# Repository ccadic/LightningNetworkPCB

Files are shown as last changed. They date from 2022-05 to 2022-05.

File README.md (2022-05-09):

# LightningNetworkPCB
This is a lightning network esp32S2 experimentation PCB (POS/ATM)

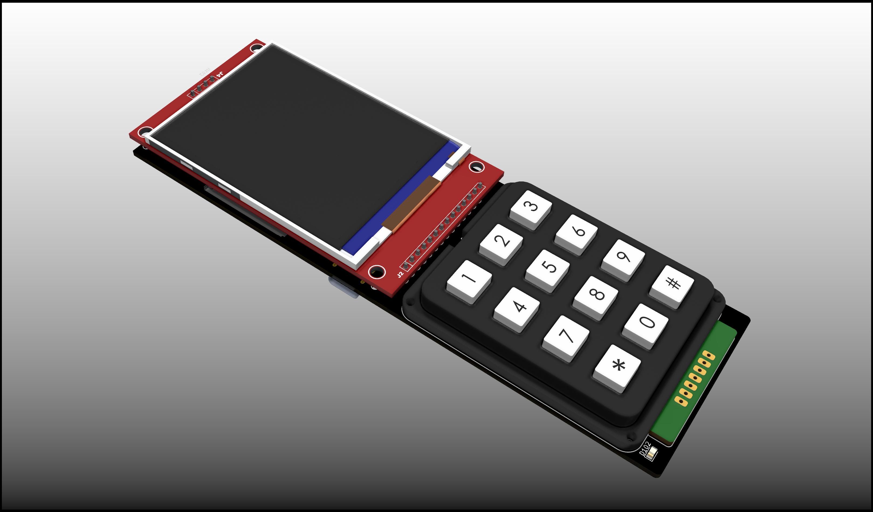
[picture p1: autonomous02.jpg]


Licence is GPL3 I never read :) But philosophy is: do what you want with it. 
If you want to encourage me, here is my BTC wallet address: bc1qdy8alfz6t623trqzk2m0mzrz8w87wwgjc9azgc
My LN Wallet: lnbc1p38nqhcpp5dr46a44fh3jh4uhenvvuxhza30jzzg2auevfjff3hw0uxne34k8qdqu2askcmr9wssx7e3q2dshgmmndp5scqzpgxqyz5vqsp5hzff9unn0vs4f9qsam9a67ffl5hydvs7n4yxd2n6f3aa29qd9jks9qyyssq4y6nllz8ku0qk05glep3g6frwyypptjahnv4t9neszszl07pl944seglzcfk7q9hreuq62wl3f8jjn4ugytncnhhm3zngr34ektzegspkv3cxk

This board is using
An ESP32-S2 wroom chip from espressif
A 2.8 inch touch screen (ILI9341 SPI)
A 3x4 keypad (https://www.amazon.fr/gp/product/B07GFDKJYZ/ref=ppx_yo_dt_b_asin_title_o08_s00?ie=UTF8&th=1)

The board is equiped with a USB-C plug to bring 5V and to upload ESP32S2 scketches
The board also has a 12v regulator thru a barrel jack, should you want to connect a 12v source and fee the coin selector with 12v.  The 12v si also converted to 3.3v for the ESP32 to run.

You have a connector for the CH-926 Coin selector. Have a look at the PCB writing (the wiring is explained)
The CH-926 coin pin is 5V. I built a level shifter to be able to talk to the ESP32 pin in 3.3v

You also have a bunch of extra GPIO / SPI and I2C connector on the top back of the PCB. It allows you to connect a TTL thermal printer, should you want to create a LN-POS
You also have extra ESP32-S TRX1 TRX0 pins to talk to another devive thru UART. I have added these to be able to talk to a CAM-ESP32, should you want to read QR code from another ESP32 device
You hace I2C SDA/SCL pins to connect, for instance, a NFC reader/writer to process payments.

Have fun

Dr Philippe CADIC
pcadic(at)gmail.com

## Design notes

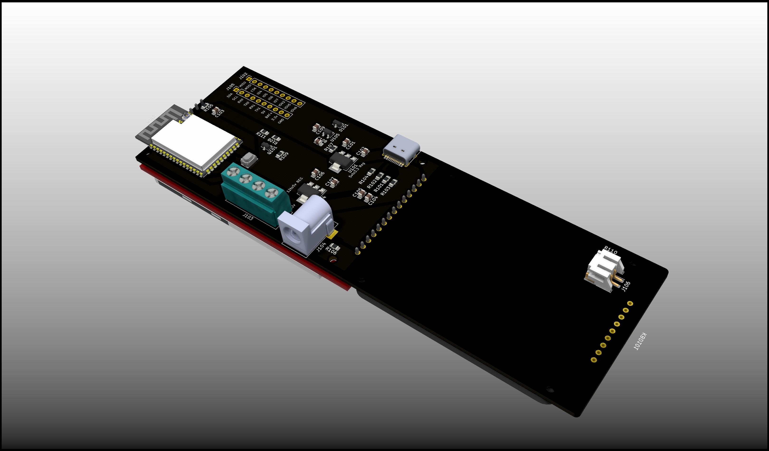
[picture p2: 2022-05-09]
autonomous3.jpg

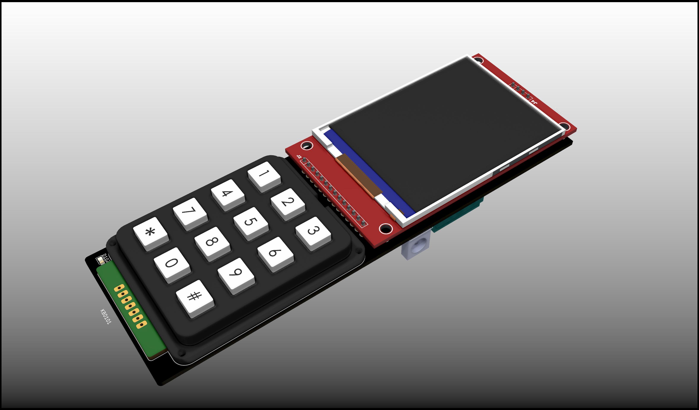
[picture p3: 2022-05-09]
autonomous2.jpg

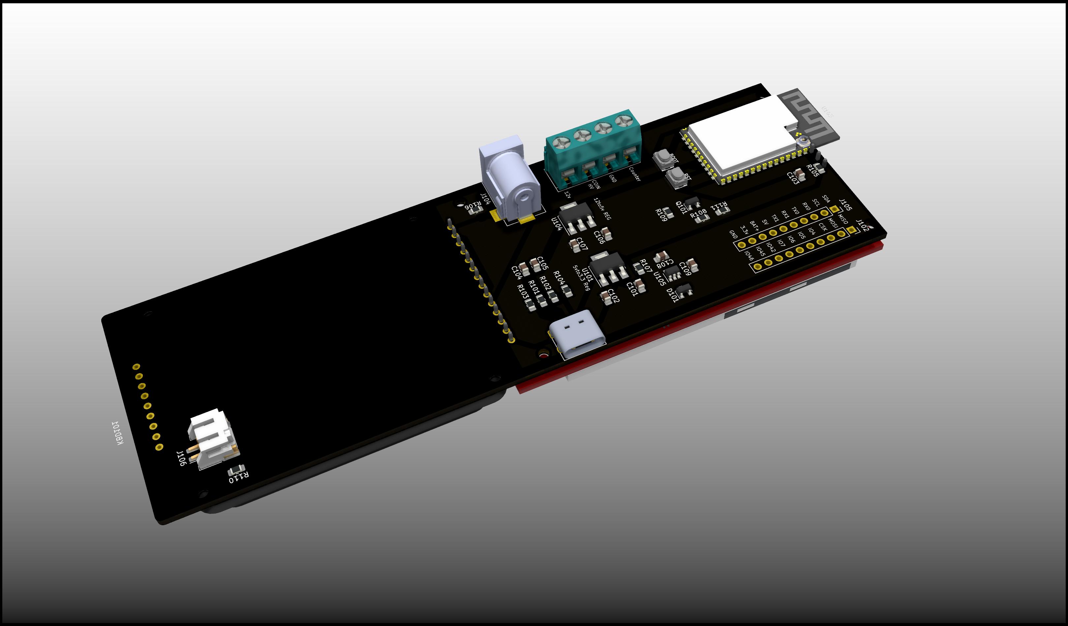
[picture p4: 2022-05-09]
autonomous.jpg

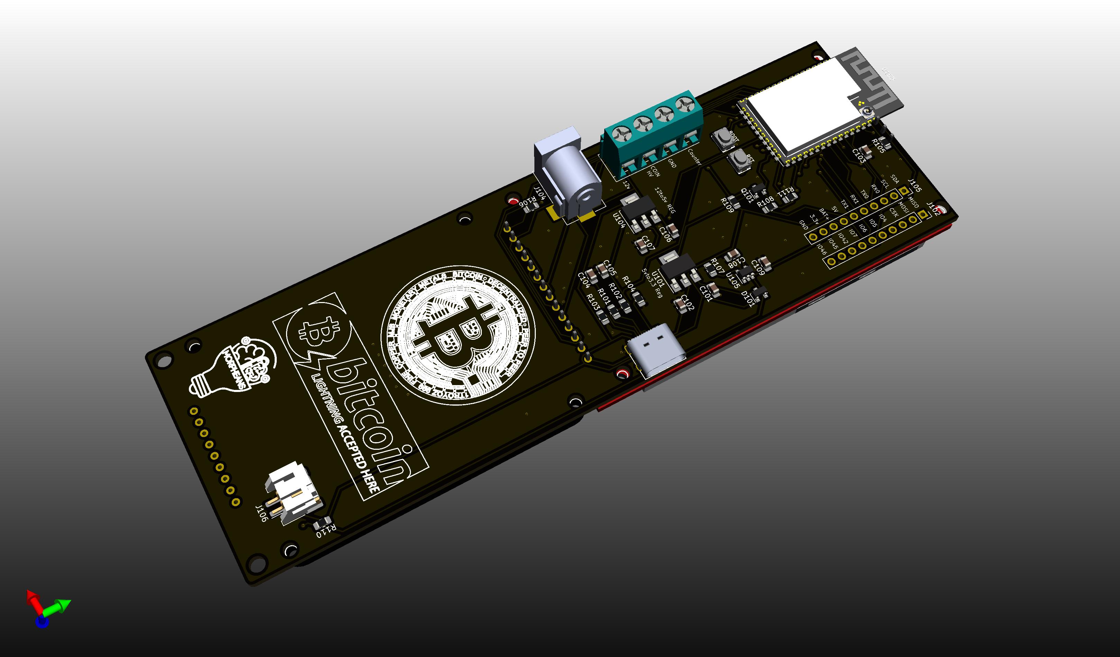
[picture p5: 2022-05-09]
autonomous4.jpg

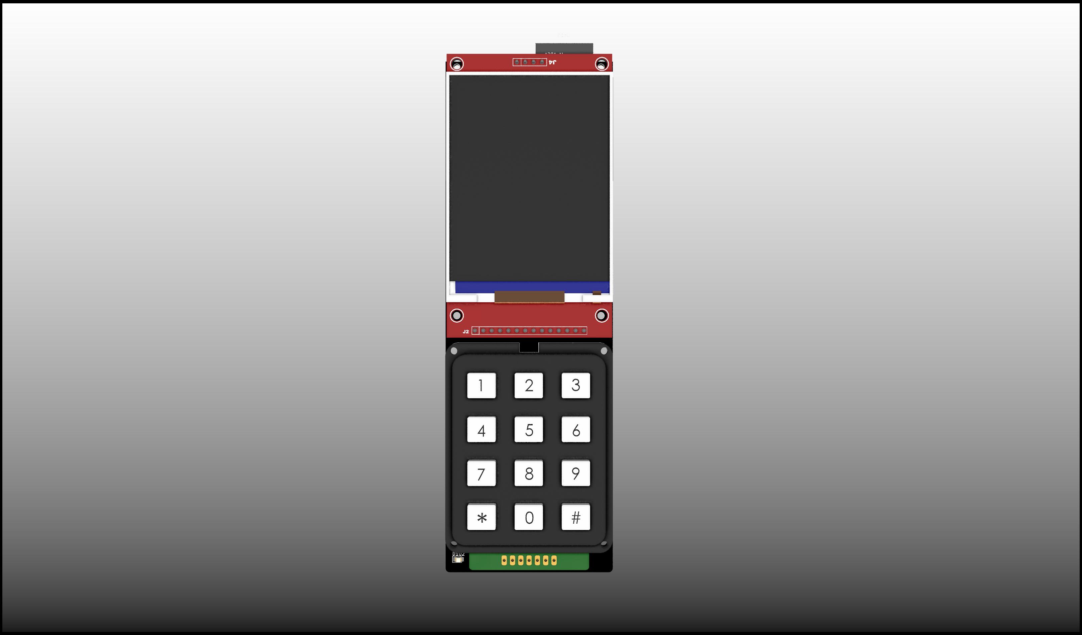
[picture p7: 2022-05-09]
autonomous0.jpg

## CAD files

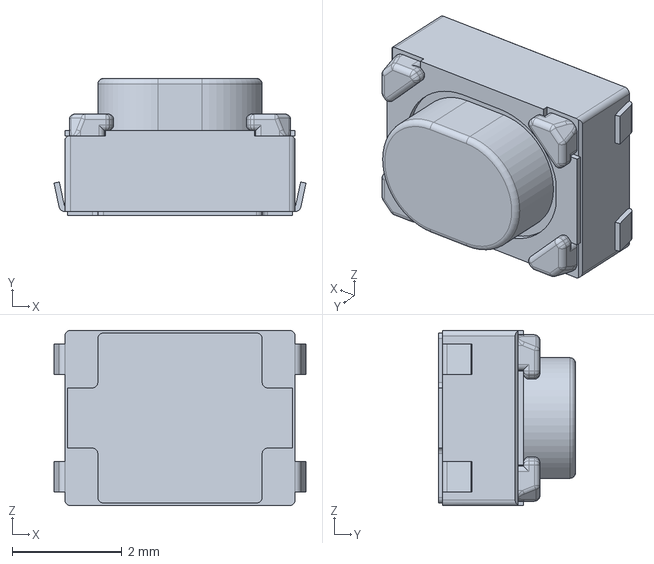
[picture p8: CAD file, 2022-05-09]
SKRPABE010.step
4.60 x 2.50 x 3.20 mm

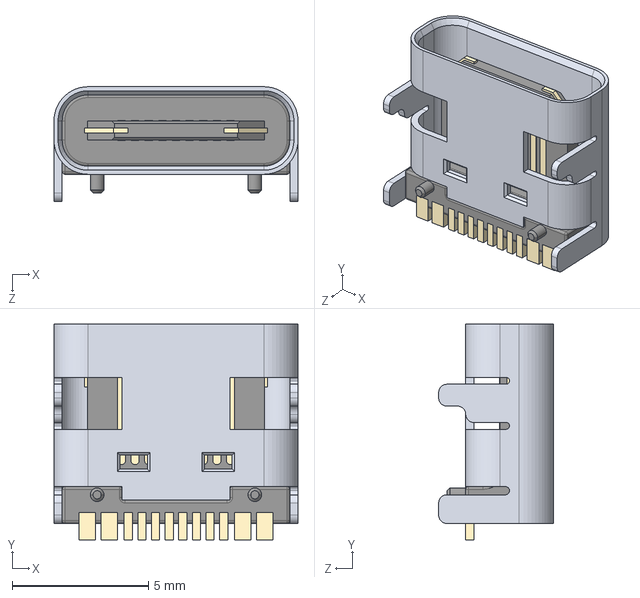
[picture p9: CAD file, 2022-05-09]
USB Type C Port (SMD Type).STEP
8.94 x 7.90 x 4.20 mm

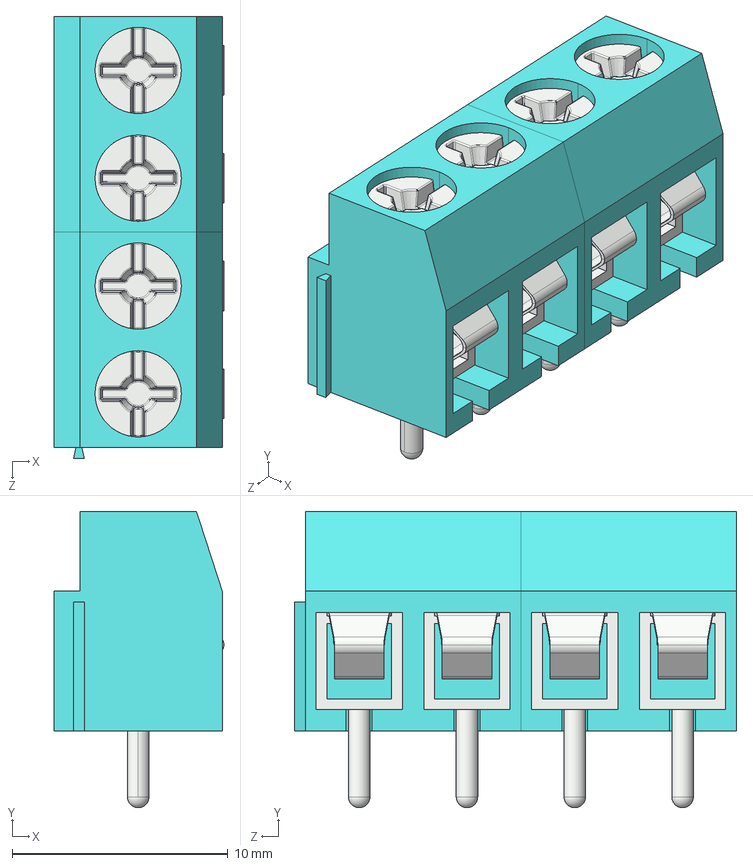
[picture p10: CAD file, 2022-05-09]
block4.STEP
7.87 x 13.8 x 20.5 mm
Outter x 2
Screw x 4
Inner x 4

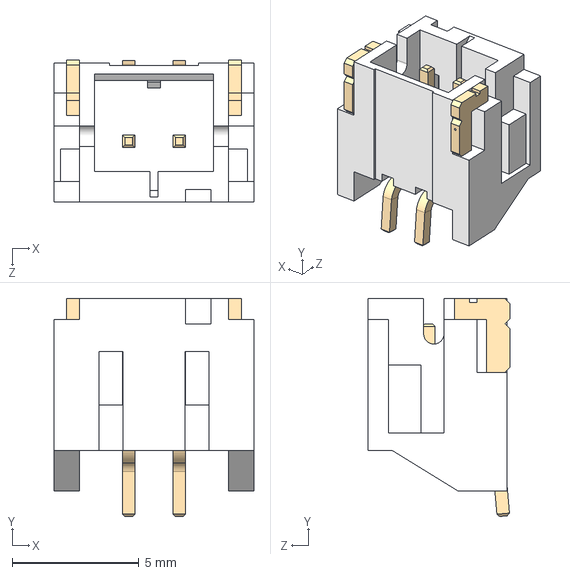
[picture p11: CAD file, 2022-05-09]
JST-S2B-PH-SM4-TB.STEP
7.90 x 8.61 x 5.61 mm

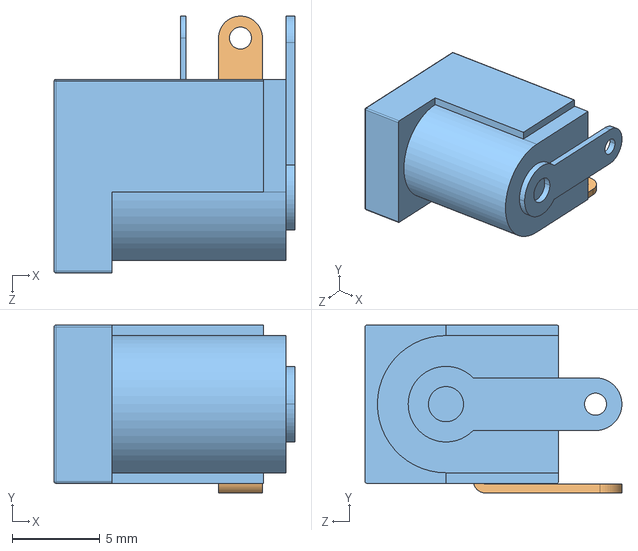
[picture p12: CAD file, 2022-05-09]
barrel.STEP
13.7 x 9.55 x 14.6 mm

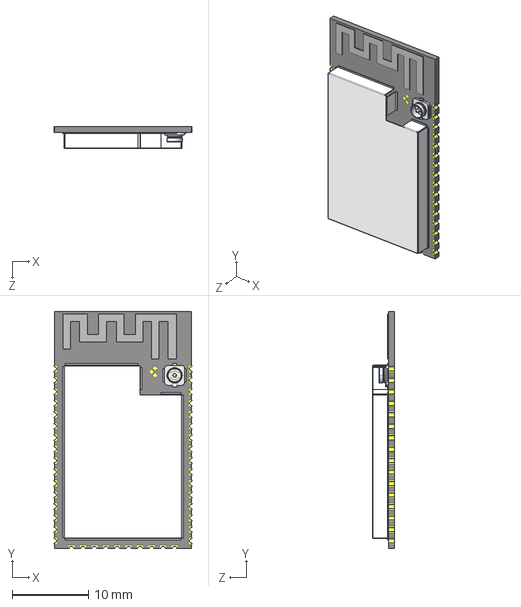
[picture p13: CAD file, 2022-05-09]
ESP32-S2-WROVER.STEP
18.0 x 31.0 x 2.91 mm

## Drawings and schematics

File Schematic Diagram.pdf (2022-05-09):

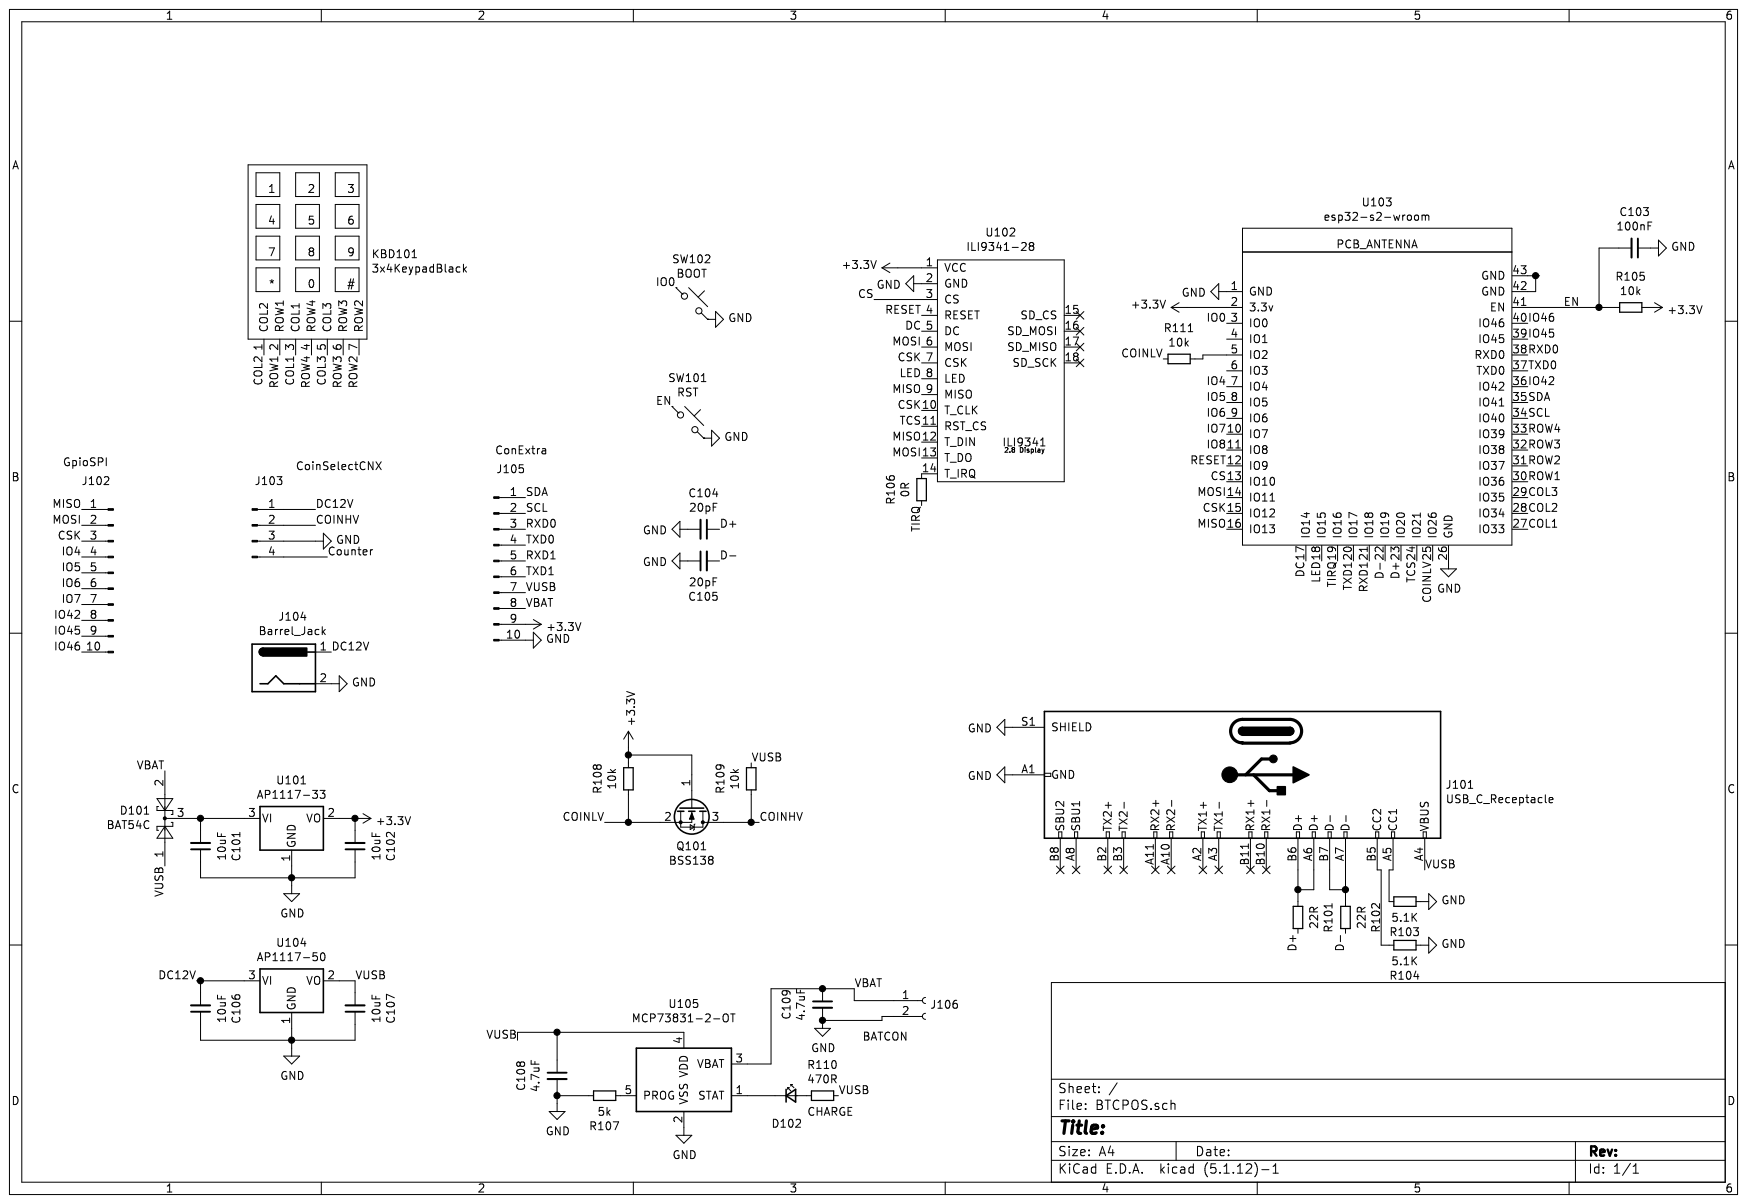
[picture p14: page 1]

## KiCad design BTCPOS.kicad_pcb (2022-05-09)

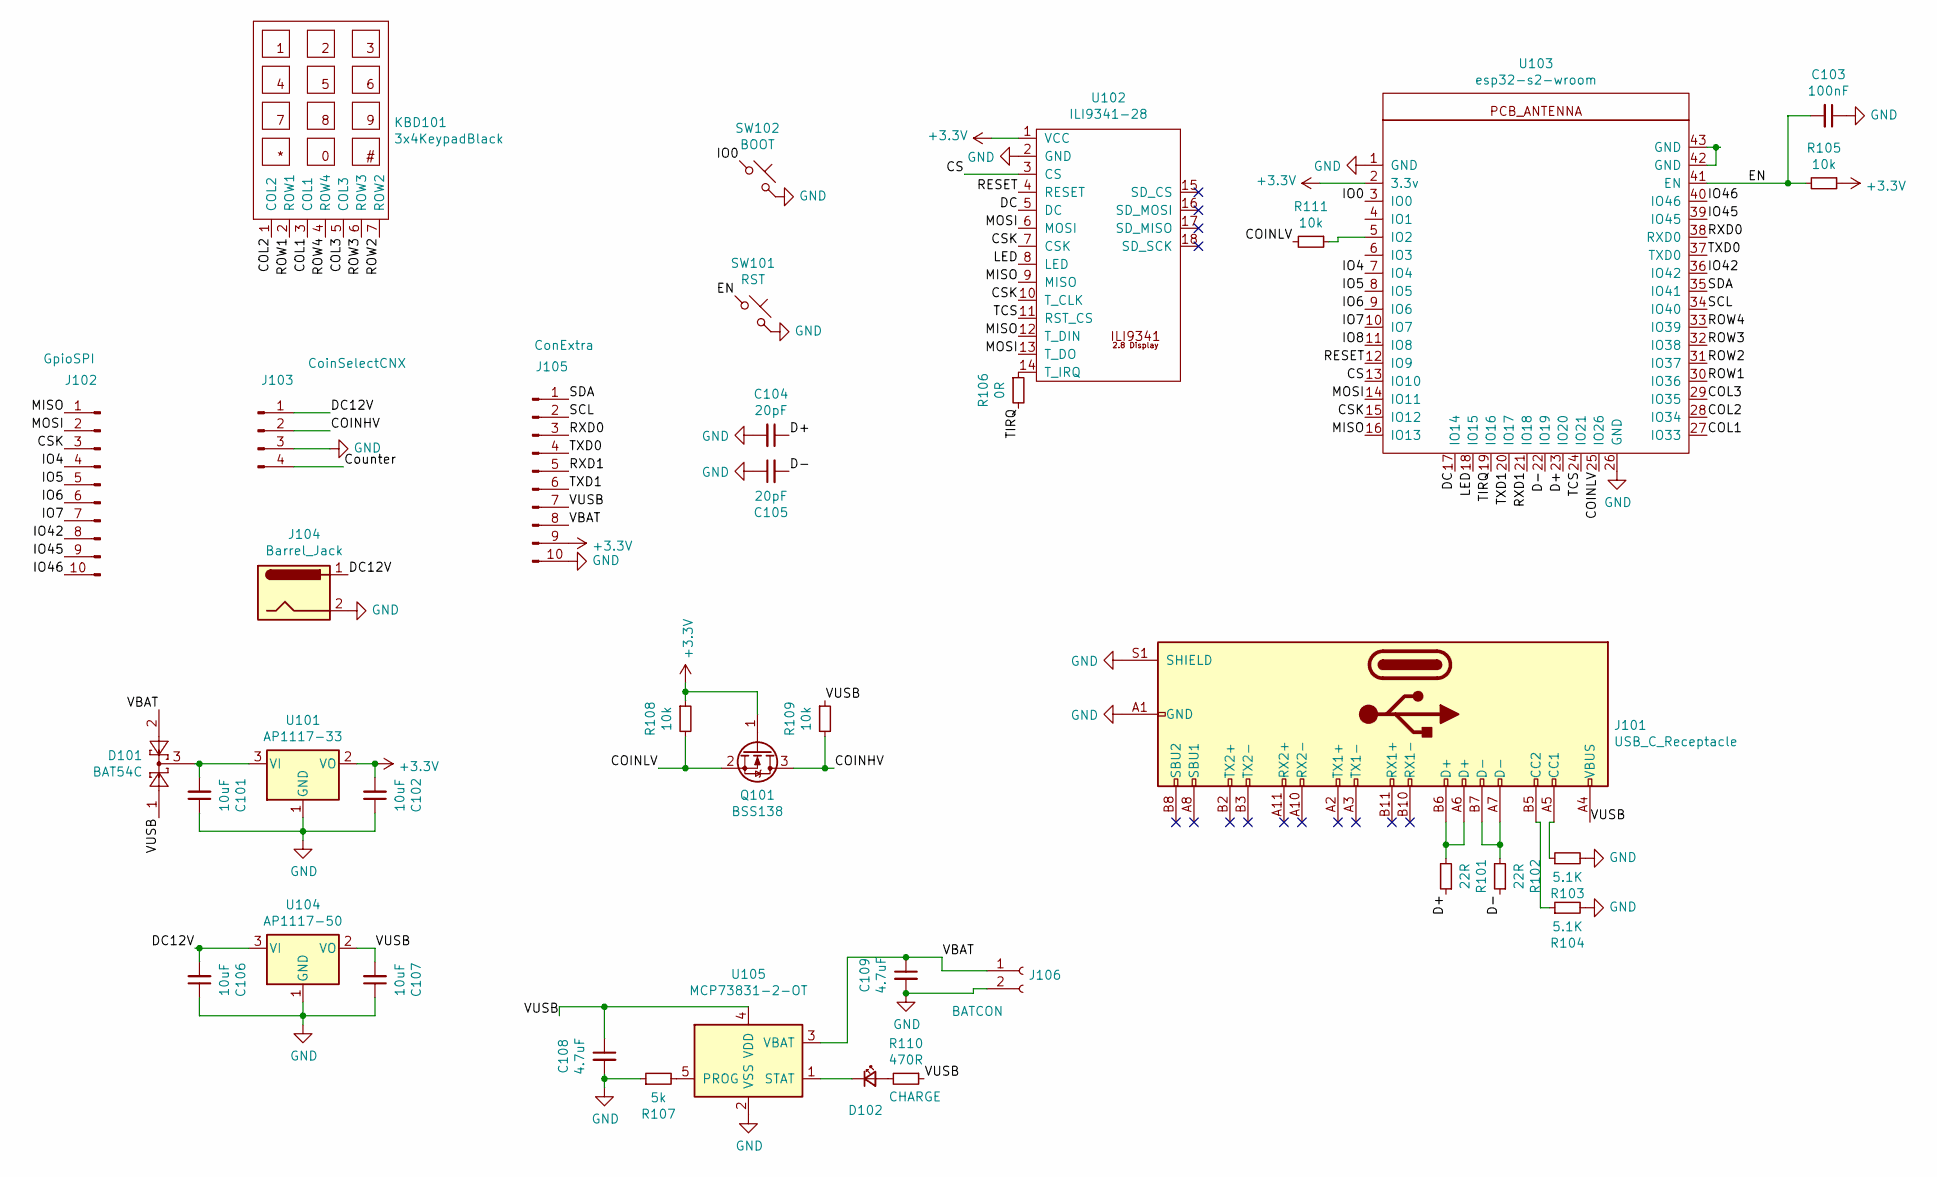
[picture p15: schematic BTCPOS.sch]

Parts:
C101, C102, C106, C107: 10uF; C_0805_2012Metric_Pad1.18x1.45mm_HandSolder
C103: 100nF; C_0805_2012Metric_Pad1.18x1.45mm_HandSolder
C104, C105: 20pF; C_0805_2012Metric_Pad1.18x1.45mm_HandSolder
C108, C109: 4.7uF; C_0805_2012Metric_Pad1.18x1.45mm_HandSolder
D101: BAT54C; SOT-23
D102: CHARGE; LED_0805_2012Metric_Pad1.15x1.40mm_HandSolder
J101: USB_C_Receptacle; GT-USB-7010
J102: GpioSPI; PinSocket_1x10_P2.54mm_Vertical
J103: CoinSelectCNX; TerminalBlock_bornier-4_P5.08mm
J104: Barrel_Jack; BARREL_JACK
J105: ConExtra; PinSocket_1x10_P2.54mm_Vertical
J106: BATCON; JST_PH_S2B-PH-SM4-TB_1x02-1MP_P2.00mm_Horizontal
KBD101: 3x4KeypadBlack; KeyPad_3x4
Q101: BSS138; SOT-23
R101, R102: 22R; R_0805_2012Metric_Pad1.20x1.40mm_HandSolder
R103, R104: 5.1K; R_0805_2012Metric_Pad1.20x1.40mm_HandSolder
R105, R108, R109, R111: 10k; R_0805_2012Metric_Pad1.20x1.40mm_HandSolder
R106: 0R; R_0805_2012Metric_Pad1.20x1.40mm_HandSolder
R107: 5k; R_0805_2012Metric_Pad1.20x1.40mm_HandSolder
R110: 470R; R_0805_2012Metric_Pad1.20x1.40mm_HandSolder
SW101: RST; SKRPABE010
SW102: BOOT; SKRPABE010
U101: AP1117-33; SOT-223-3_TabPin2
U102: ILI9341-28; ILI9341-2_8-noSD
U103: esp32-s2-wroom; esp32-s2-wrooom
U104: AP1117-50; SOT-223-3_TabPin2
U105: MCP73831-2-OT; SOT-23-5

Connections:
+3V3: C102.2, J105.9, Q101.1 (G), R105.1, R108.1, U101.2 (VO), U102.1 (VCC), U103.2 (3.3v)
/COINHV: J103.2, Q101.3 (D), R109.2
/COINLV: Q101.2 (S), R108.2, R111.2, U103.25 (IO26)
/COL1: KBD101.3 (COL1), U103.27 (IO33)
/COL2: KBD101.1 (COL2), U103.28 (IO34)
/COL3: KBD101.5 (COL3), U103.29 (IO35)
/CS: U102.3 (CS), U103.13 (IO10)
/CSK: J102.3, U102.7 (CSK), U102.10 (T_CLK), U103.15 (IO12)
/D+: C104.1, R101.1, U103.23 (IO20)
/D-: C105.2, R102.1, U103.22 (IO19)
/DC: U102.5 (DC), U103.17 (IO14)
/DC12V: C106.2, J103.1, J104.1, U104.3 (VI)
/EN: C103.2, R105.2, SW101.1, U103.41 (EN)
/IO0: SW102.1, U103.3 (IO0)
/IO4: J102.4, U103.7 (IO4)
/IO5: J102.5, U103.8 (IO5)
/IO6: J102.6, U103.9 (IO6)
/IO7: J102.7, U103.10 (IO7)
/IO42: J102.8, U103.36 (IO42)
/IO45: J102.9, U103.39 (IO45)
/IO46: J102.10, U103.40 (IO46)
/LED: U102.8 (LED), U103.18 (IO15)
/MISO: J102.1, U102.9 (MISO), U102.12 (T_DIN), U103.16 (IO13)
/MOSI: J102.2, U102.6 (MOSI), U102.13 (T_DO), U103.14 (IO11)
/RESET: U102.4 (RESET), U103.12 (IO9)
/ROW1: KBD101.2 (ROW1), U103.30 (IO36)
/ROW2: KBD101.7 (ROW2), U103.31 (IO37)
/ROW3: KBD101.6 (ROW3), U103.32 (IO38)
/ROW4: KBD101.4 (ROW4), U103.33 (IO39)
/RXD0: J105.3, U103.38 (RXD0)
/RXD1: J105.5, U103.21 (IO18)
/SCL: J105.2, U103.34 (IO40)
/SDA: J105.1, U103.35 (IO41)
/TCS: U102.11 (RST_CS), U103.24 (IO21)
/TIRQ: R106.2, U103.19 (IO16)
/TXD0: J105.4, U103.37 (TXD0)
/TXD1: J105.6, U103.20 (IO17)
/VBAT: C109.1, D101.2, J105.8, J106.1, U105.3 (VBAT)
/VUSB: C107.2, C108.1, D101.1, J101.A4 (VBUS), J101.A9 (VBUS), J101.B4 (VBUS), J101.B9 (VBUS), J105.7, R109.1, R110.1, U104.2 (VO), U105.4 (VDD)
GND: C101.1, C102.1, C103.1, C104.2, C105.1, C106.1, C107.1, C108.2, C109.2, J101.A1 (GND), J101.A12 (GND), J101.B1 (GND), J101.B12 (GND), J101.S1 (SHIELD), J103.3, J104.2, J105.10, J106.2, R103.2, R104.2, R107.1, SW101.2, SW102.2, U101.1 (GND), U102.2 (GND), U103.1 (GND), U103.26 (GND), U104.1 (GND), U105.2 (VSS)
unnamed: C101.2, D101.3, U101.3 (VI)
unnamed: D102.1 (K), U105.1 (STAT)
unnamed: D102.2 (A), R110.2
unnamed: J101.A5 (CC1), R103.1
unnamed: J101.A6 (D+), J101.B6 (D+), R101.2
unnamed: J101.A7 (D-), J101.B7 (D-), R102.2
unnamed: J101.B5 (CC2), R104.1
unnamed: R106.1, U102.14 (T_IRQ)
unnamed: R107.2, U105.5 (PROG)
unnamed: R111.1, U103.5 (IO2)
unnamed: U103.42 (GND), U103.43 (GND)

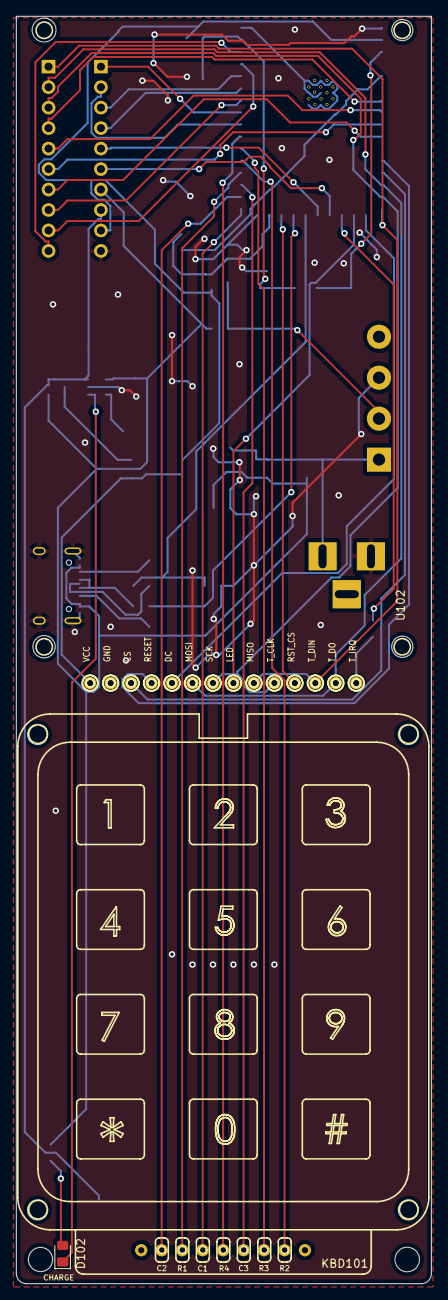
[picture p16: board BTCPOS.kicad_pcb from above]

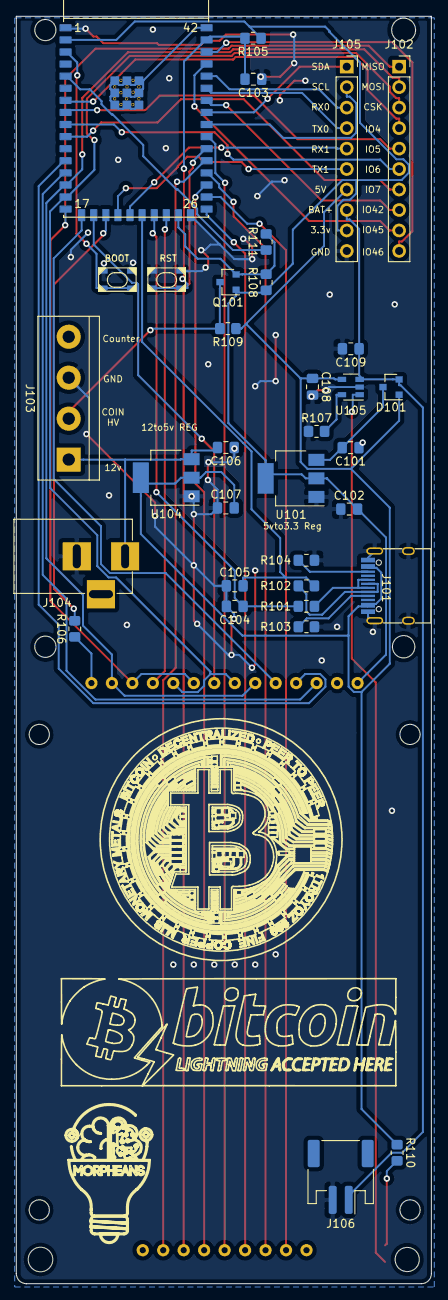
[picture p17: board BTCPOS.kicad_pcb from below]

Board: 2 copper layers, 51.5 x 157.2 mm, 38 parts (35 on the bottom side), 51 nets.

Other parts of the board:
REF10: BTC6
